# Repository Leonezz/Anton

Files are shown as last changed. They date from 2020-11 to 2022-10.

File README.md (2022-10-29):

# Anton

Anton is a custom keyboard project.

All what you need to build a keyboard is/will be in this repo.

## Details

Anton is a comtom design keyboard, it is based on STM32F103C8T6 MCU and QMK firmware. In this repo, all files(PCB, mechanical structure and code) are included.All what you need to do to make a same keyboard is clone all this files and make all things by taobao.com. 

# Features

- WS2812 RGB Lighting
- ~~Bluetooth(TODO)~~

# 2022-10-29 EDIT

After 4 keyboards made out this design and 2 years of use, I hereby announce this project a success.

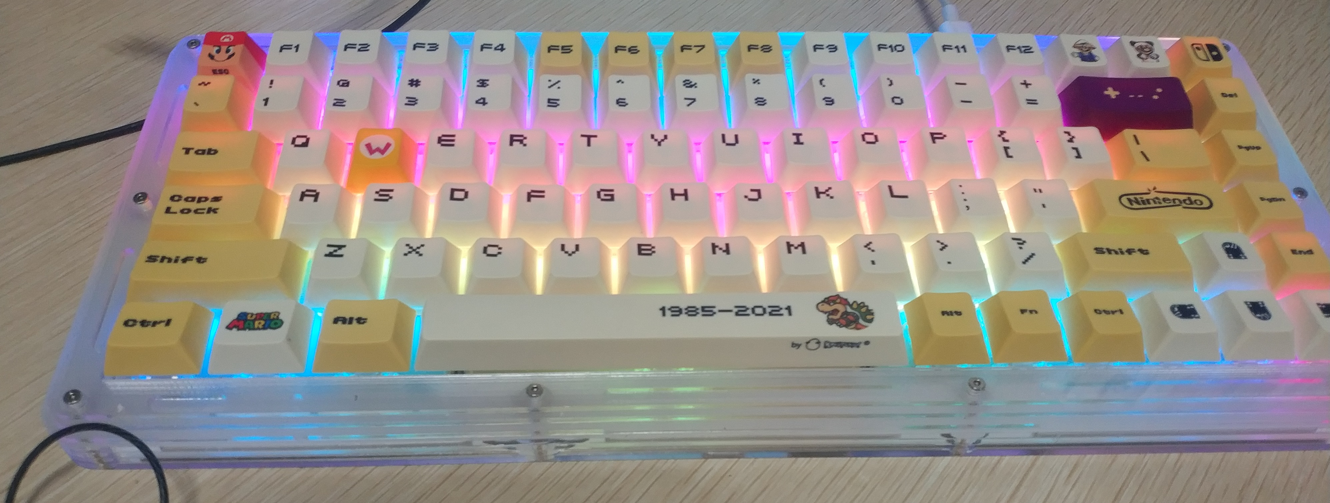
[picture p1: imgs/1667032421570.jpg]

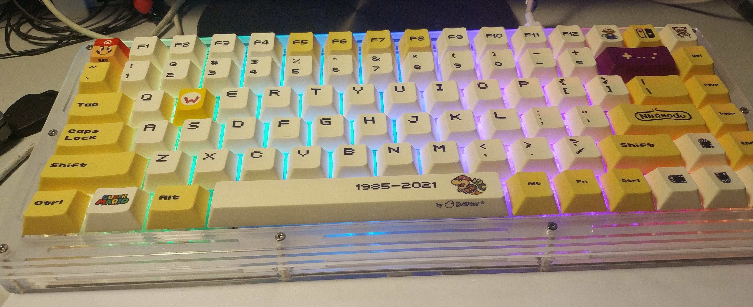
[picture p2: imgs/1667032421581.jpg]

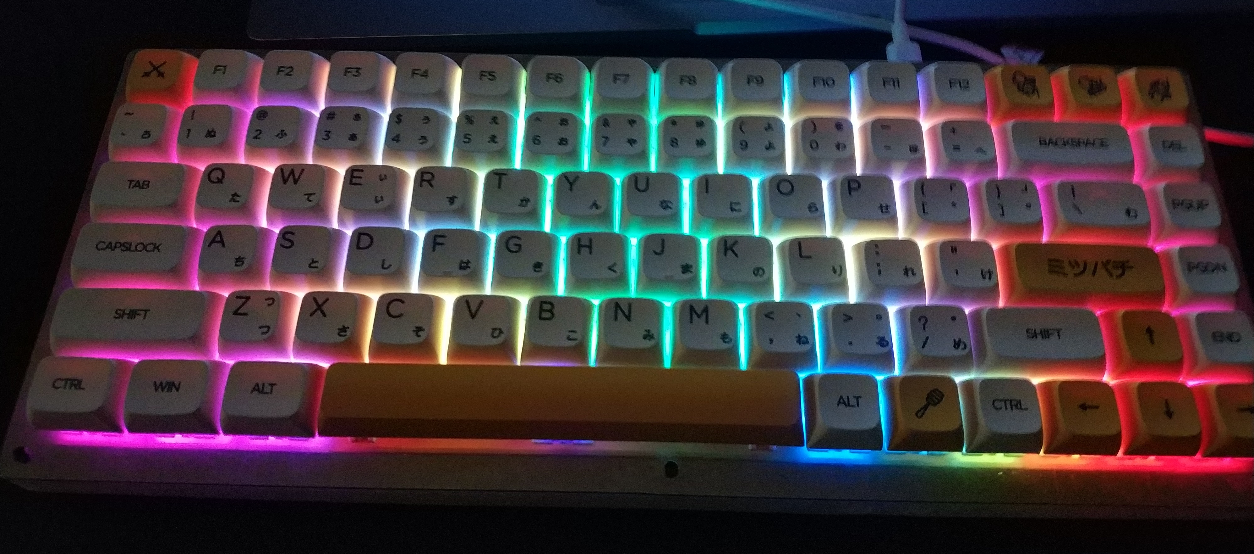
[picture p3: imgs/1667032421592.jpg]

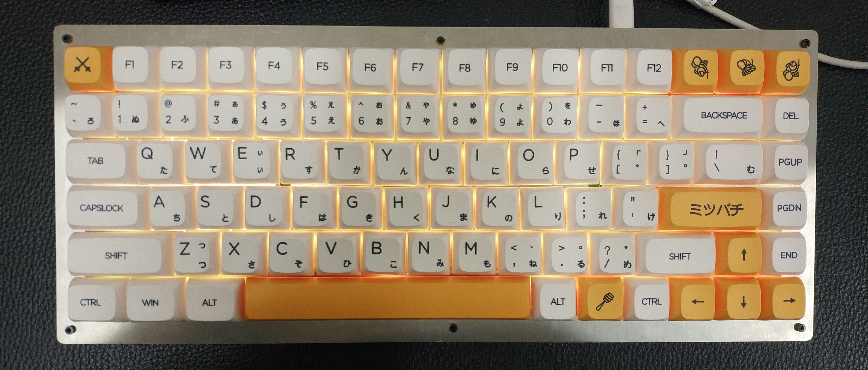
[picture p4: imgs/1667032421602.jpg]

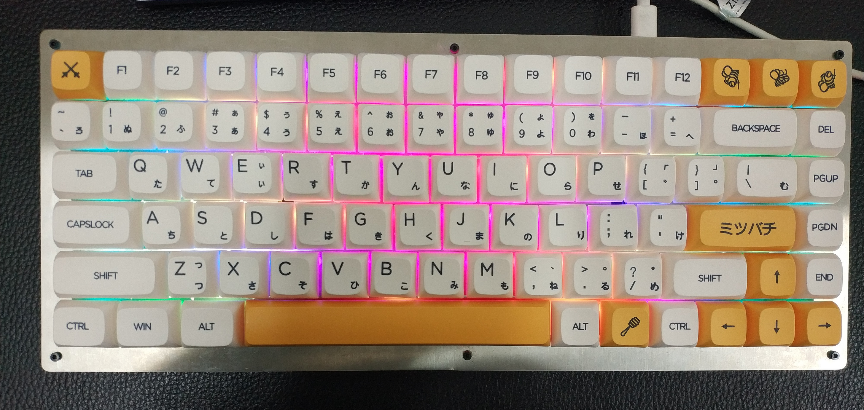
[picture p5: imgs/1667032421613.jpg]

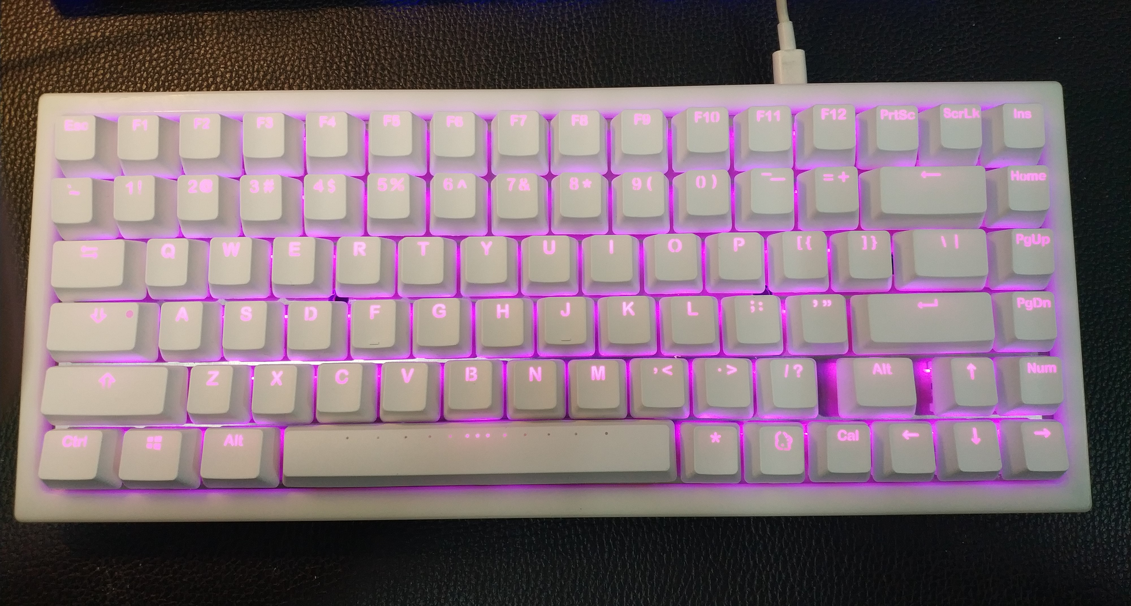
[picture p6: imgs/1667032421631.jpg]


# License

GPL

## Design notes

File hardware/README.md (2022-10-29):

# Hardware

keyboard hardware files, PCB circuit in folder `PCB` and shall 3D model in folder `structure`.

# Note

I am an amateur in all these design area,please check the files before actual manufacturing.

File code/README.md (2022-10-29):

keyboard firmware,running on stm32f103c8t6 MCU.

based on the opensource keyboard firmware [QMK](https://github.com/qmk/qmk_firmware)

the firmware for this very keyboard is [here](https://github.com/Leonezz/qmk_firmware/tree/master/keyboards/anton)

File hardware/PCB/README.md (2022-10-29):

# 使用立创EDA编辑

# Features

- Bluetooth
- type-c off board interface
- ws2812 RGB matrix
- hot swap switches

# What Can be Improved

- type-c sub board and battary interface too thin
- bluetooth module in bad position,it's batter to place it to the edge of board
- ws2812 package too tight,hard to put the element in
- swd download interface in bad position,better to the edge
- the on board power design is a failure, I have to use a off board one

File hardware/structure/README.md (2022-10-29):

# Structure

the shell 3D models are in this folder, you can use the stl files in folder `shell/stl` if you don't use `Solidworks`(all models are designed by it).

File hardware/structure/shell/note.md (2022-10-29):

轴:5mm
定位板:1.5mm
PCB:1.6mm
轴座:1.8mm

定位板下面到外壳上面至少:3.5+1.6+1.8 = 6.9

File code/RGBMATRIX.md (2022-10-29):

# REBMATRIX effects 中英文对照

```c
enum rgb_matrix_effects {
RGB_MATRIX_NONE = 0,
RGB_MATRIX_SOLID_COLOR = 1, // Static single hue, no speed support静态单色调无速度支持
RGB_MATRIX_ALPHAS_MODS, // Static dual hue, speed is hue for secondary hue静态双重色调速度为次要色调
RGB_MATRIX_GRADIENT_UP_DOWN, // Static gradient top to bottom, speed controls how much gradient changes静态渐变从上到下速度控制渐变量
RGB_MATRIX_GRADIENT_LEFT_RIGHT, // Static gradient left to right, speed controls how much gradient changes静态梯度从左到右速度控制梯度的变化量
RGB_MATRIX_BREATHING, // Single hue brightness cycling animation单色调亮度循环动画
RGB_MATRIX_BAND_SAT, // Single hue band fading saturation scrolling left to right左色调向右滚动单个色相带衰减饱和度
RGB_MATRIX_BAND_VAL, // Single hue band fading brightness scrolling left to right单个色相带衰减亮度从左向右滚动
RGB_MATRIX_BAND_PINWHEEL_SAT, // Single hue 3 blade spinning pinwheel fades saturation单色调3叶片旋转风车褪色饱和度
RGB_MATRIX_BAND_PINWHEEL_VAL, // Single hue 3 blade spinning pinwheel fades brightness单色调3叶片旋转风车减弱亮度
RGB_MATRIX_BAND_SPIRAL_SAT, // Single hue spinning spiral fades saturation单色调旋转螺旋褪色饱和度
RGB_MATRIX_BAND_SPIRAL_VAL, // Single hue spinning spiral fades brightness单色调旋转螺旋淡出亮度
RGB_MATRIX_CYCLE_ALL, // Full keyboard solid hue cycling through full gradient全键盘纯色在整个渐变中循环
RGB_MATRIX_CYCLE_LEFT_RIGHT, // Full gradient scrolling left to right从左到右全梯度滚动
RGB_MATRIX_CYCLE_UP_DOWN, // Full gradient scrolling top to bottom全梯度从上到下滚动
RGB_MATRIX_CYCLE_OUT_IN, // Full gradient scrolling out to in全梯度滚动到
RGB_MATRIX_CYCLE_OUT_IN_DUAL, // Full dual gradients scrolling out to in全双梯度滚动到
RGB_MATRIX_RAINBOW_MOVING_CHEVRON, // Full gradent Chevron shapped scrolling left to right全渐变雪佛龙形从左到右滚动
RGB_MATRIX_CYCLE_PINWHEEL, // Full gradient spinning pinwheel around center of keyboard围绕键盘中心的全梯度旋转风车
RGB_MATRIX_CYCLE_SPIRAL, // Full gradient spinning spiral around center of keyboard围绕键盘中心的全梯度旋转螺旋
RGB_MATRIX_DUAL_BEACON, // Full gradient spinning around center of keyboard全梯度围绕键盘中心旋转
RGB_MATRIX_RAINBOW_BEACON, // Full tighter gradient spinning around center of keyboard围绕键盘中心的旋转更加紧密
RGB_MATRIX_RAINBOW_PINWHEELS, // Full dual gradients spinning two halfs of keyboard全双梯度旋转两半键盘
RGB_MATRIX_RAINDROPS, // Randomly changes a single key's hue随机更改单个键的色调
RGB_MATRIX_JELLYBEAN_RAINDROPS, // Randomly changes a single key's hue and saturation随机更改单个键的色相和饱和度
#if define(RGB_MATRIX_FRAMEBUFFER_EFFECTS)
RGB_MATRIX_TYPING_HEATMAP, // How hot is your WPM!您的WPM有多热
RGB_MATRIX_DIGITAL_RAIN, // That famous computer simulation那著名的计算机模拟
#endif
#if defined(RGB_MATRIX_KEYPRESSES) || defined(RGB_MATRIX_KEYRELEASES)
RGB_MATRIX_SOLID_REACTIVE_SIMPLE, // Pulses keys hit to hue & value then fades value out脉冲键击中色相和值然后淡出值
RGB_MATRIX_SOLID_REACTIVE, // Static single hue, pulses keys hit to shifted hue then fades to current hue静态单一色相脉冲键敲击以改变色相然后淡出为当前色相
RGB_MATRIX_SOLID_REACTIVE_WIDE // Hue & value pulse near a single key hit then fades value out一次按键时的色相和数值脉冲然后淡出数值
RGB_MATRIX_SOLID_REACTIVE_MULTIWIDE // Hue & value pulse near multiple key hits then fades value out多次击键时的色相和数值脉冲然后淡出数值
RGB_MATRIX_SOLID_REACTIVE_CROSS // Hue & value pulse the same column and row of a single key hit then fades value out色相和值在一次击键时以相同的列和行脉冲然后淡出值
RGB_MATRIX_SOLID_REACTIVE_MULTICROSS // Hue & value pulse the same column and row of multiple key hits then fades value out色相和值在多个击键的相同列和行上脉冲然后淡出值
RGB_MATRIX_SOLID_REACTIVE_NEXUS // Hue & value pulse away on the same column and row of a single key hit then fades value out色相和数值在一次击键的同一列和同一行上消失然后淡出数值
RGB_MATRIX_SOLID_REACTIVE_MULTINEXUS // Hue & value pulse away on the same column and row of multiple key hits then fades value out色相和值在多个击键的同一列和同一行上消失然后淡出值
RGB_MATRIX_SPLASH, // Full gradient & value pulse away from a single key hit then fades value out完整的梯度和数值脉冲远离单个按键然后淡出数值
RGB_MATRIX_MULTISPLASH, // Full gradient & value pulse away from multiple key hits then fades value out完整的渐变和价值脉冲远离多个击键然后淡出价值
RGB_MATRIX_SOLID_SPLASH, // Hue & value pulse away from a single key hit then fades value out色相和价值脉冲远离单个击键然后淡出价值
RGB_MATRIX_SOLID_MULTISPLASH, // Hue & value pulse away from multiple key hits then fades value out色相和价值脉冲远离多个击键然后淡出价值
#endif
RGB_MATRIX_EFFECT_MAX
};
```

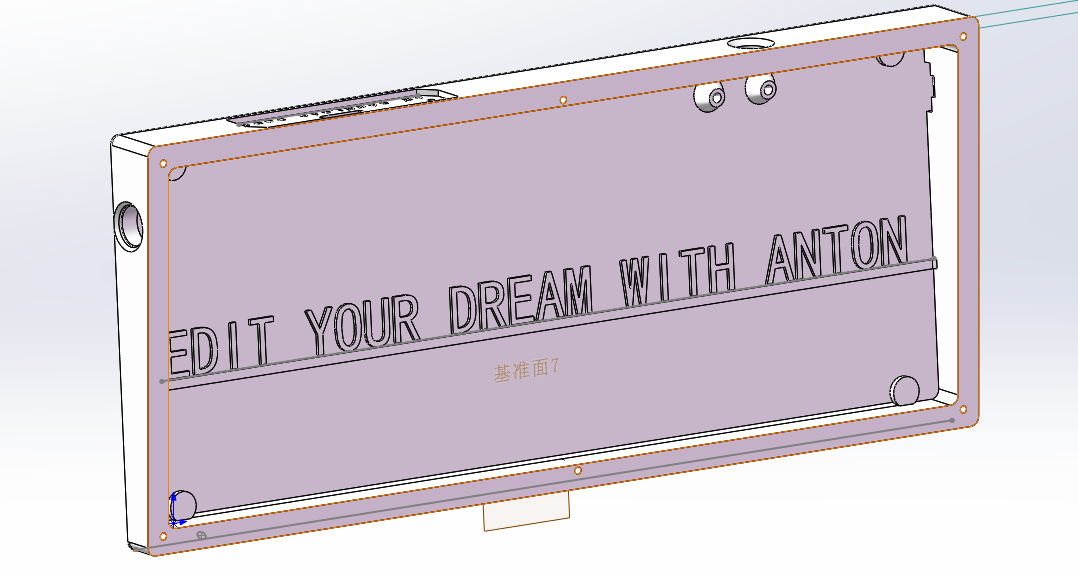
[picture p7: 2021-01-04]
hardware/structure/shell/imgs/down.png

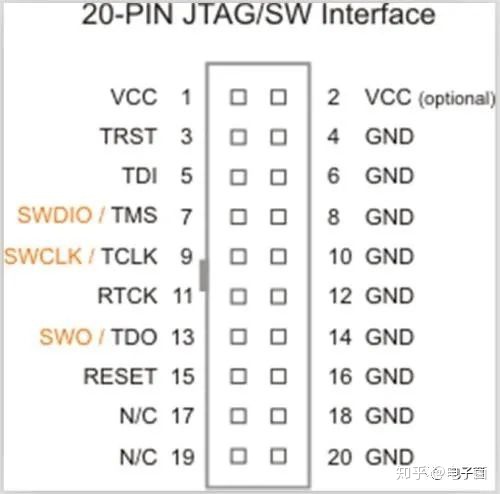
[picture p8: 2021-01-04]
hardware/structure/img/J-Tag.jpg

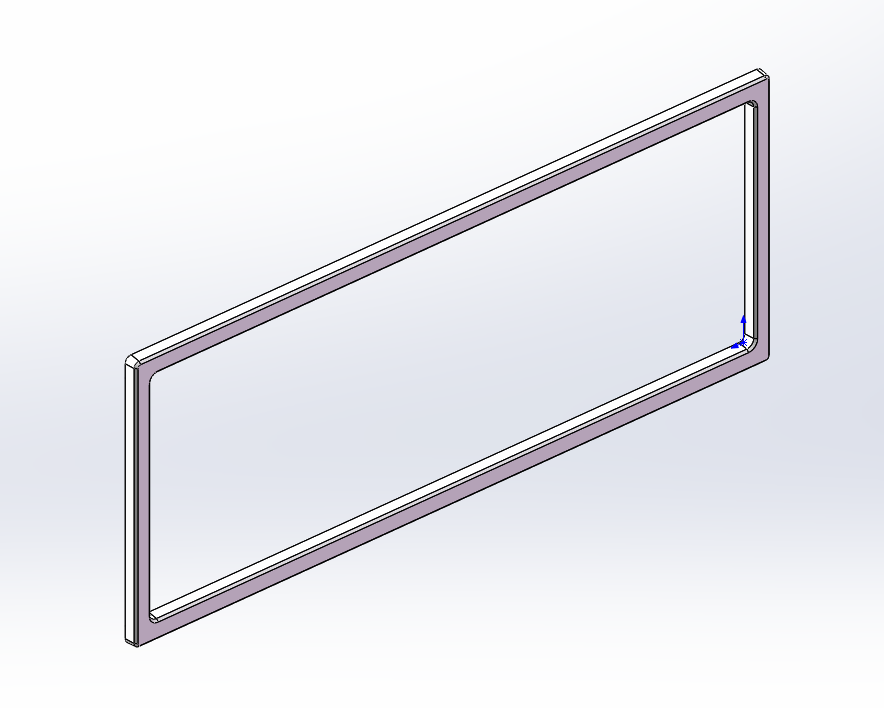
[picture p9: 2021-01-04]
hardware/structure/shell/imgs/up.png

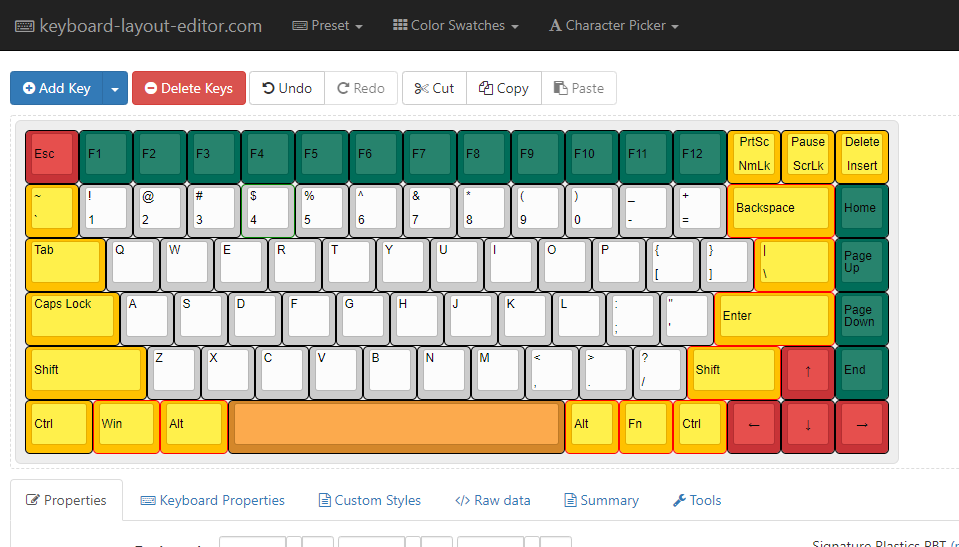
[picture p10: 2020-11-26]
hardware/structure/img/look.jpg

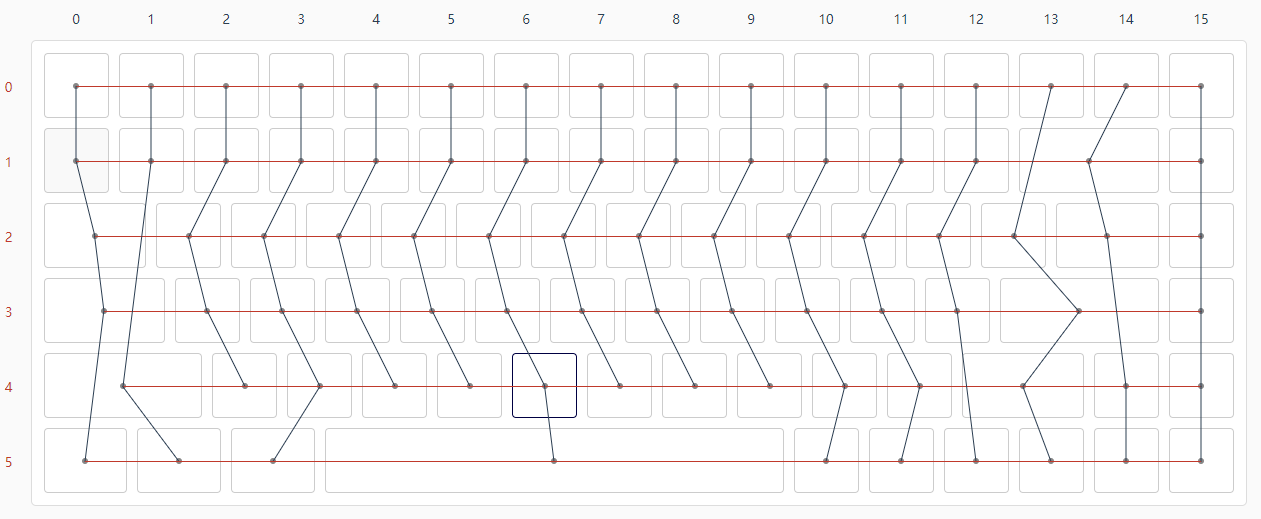
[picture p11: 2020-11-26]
hardware/structure/matrix.png

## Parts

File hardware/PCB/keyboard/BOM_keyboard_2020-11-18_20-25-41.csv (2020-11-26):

ID | Name | Designator | Footprint | Quantity | Manufacturer Part | Manufacturer | Supplier | Supplier Part | _Price | LCSC Assembly
1 | Switch3x4x2 | BOOT,RESET | KEY-3.0*4.0 | 2 | Switch3x4x2 | ReliaPro | LCSC | C26638 | ￥0.21811
2 | 10K | R11 | R0805 | 1 | TR0805B10KP0525 | Ever Ohms Tech | LCSC | C188360 | ￥0.118193
3 | 2.54MM-4P | H1 | HDR-TH_4P-P2.54-V | 1 | 210-91-04GB01 | PINREX | LCSC | C390680 | ￥0.068036
4 | MF-NSMF050-2 | FF | F1206 | 1 | MF-NSMF050-2 | BOURNS | LCSC | C75464 | ￥0.185259 | Yes
5 | btk-05 | M1 | BTK-05-BLUTEETH | 1
6 | 300 | R10 | R0805 | 1 | RMCF0805JT300R | Stackpole Elec | LCSC | C237136 | ￥0.042691
7 | LED0805-GD | STDBY_LED | LED0805-RD | 1 | LED0805-GD | ARKLED | LCSC | C107402 | ￥0.0835 | Yes
8 | CHERRYMX 2U 卫星轴 COPY | K2 | CHERRY_MX_2U_卫星轴 | 1 | Cherry MX
9 | 100nF | C18,C16,C20,C7,C9,C17 | C0603 | 6 | GRM188R11C104KA01D | MuRata | LCSC | C86004 | ￥0.105227
10 | 10uH | L1 | IND-SMD_L4.6-W4.1 | 1 | MHCI04020-100M-R8 | Chilisin Elec | LCSC | C285744 | ￥2
11 | 22 | R1,R2 | R0603 | 2 | 0603WAF220JT5E | UniOhm | LCSC | C23345 | ￥0.005856 | Yes
12 | FC-2012HYK-588J | LED5 | LED0805-FD | 1 | FC-2012HYK-588J | NATIONSTAR | LCSC | C84261 | ￥0.117 | Yes
13 | 22uF | C25,C24 | C1206 | 2 | CL31A226KOHNNNE | SAMSUNG | LCSC | C90146 | ￥0.209598 | Yes
14 | STM32F103C8T6 | U5 | LQFP-48_L7.0-W7.0-P0.50-LS9.0-BL | 1 | STM32F103C8T6 | STMicroelectronics | LCSC | C8734 | ￥14.18 | Yes
15 | 1.25T-4PWT | CN2 | CONN-SMD_4P-P1.25_1.25T-4PWT | 1 | 1.25T-4PWT | BOOMELE | LCSC | C31597 | ￥0.238058
16 | FC-2012HRK-620D | LED7 | LED0805-RD | 1 | FC-2012HRK-620D | NATIONSTAR | LCSC | C84256 | ￥0.1105 | Yes
17 | A1254WR-S-2P | U3 | CONN-SMD_A1254WR-S-2P | 1 | A1254WR-S-2P | Changjiang Connectors | LCSC | C272975 | ￥1.5
18 | 22pF | C14,C15 | C0805 | 2 | 0805CG220J500NT | FH | LCSC | C24658 | ￥0.03805
19 | 1uF | C1,C2 | C0603 | 2 | CL10A105KB8NNNC | SAMSUNG | LCSC | C15849 | ￥0.041494 | Yes
20 | SOD4002-SH | D167,D166,D165,D164,D163,D162,D161,D160,D159,D158,D157,D156,D155,D154,D153,D152,D151,D143,D150,D149,D85,D1,D86,D87,D88,D89,D90,D91,D92,D93,D94,D95,D96,D97,D98,D99,D100,D101,D102,D103,D104,D105,D106,D107,D108,D109,D110,D111,D112,D113,D114,D115,D116,D117,D118,D119,D120,D121,D122,D123,D124,D125,D126,D127,D128,D129,D130,D131,D132,D133,D134,D135,D136,D137,D138,D139,D140,D141,D142,D148,D144,D145,D146,D147 | SOD-123F_L2.8-W1.8-LS3.7-RD | 84 | SOD4002-SH | LRC | LCSC | C154996 | ￥0.1185 | Yes
21 | FC-A2012BK-470H2 | LED4 | LED0805-RD | 1 | FC-A2012BK-470H2 | NATIONSTAR | LCSC | C84259 | ￥0.13 | Yes
22 | TP5400 | U7 | SOIC-8_L5.0-W4.0-P1.27-LS6.0-BL-EP | 1 | TP5400 | TOPPOWER | LCSC | C24154 | ￥1.1846 | Yes
23 | LM1117S-3.3 | U6 | SOT-223-3_L6.5-W3.4-P2.30-LS7.0-BR | 1 | LM1117S-3.3 | HTC | LCSC | C126027 | ￥1 | Yes
24 | PRTR5V0U2X | D2 | SOT-143_L2.9-W1.3-P1.92-LS2.3-BL | 1 | PRTR5V0U2X | Yenji Elec | LCSC | C330092 | ￥0.4999
25 | 1.1K | R12 | R0805 | 1 | 0805W8J0112T5E | Uniroyal Elec | LCSC | C246845 | ￥0.011479
26 | SS34_C432300 | D3 | SMA_L4.4-W2.8-LS5.4-RD | 1 | SS34 | LGE | LCSC | C432300 | ￥0.22135 | Yes
27 | 12MHz | X2 | HC-49S_L11.4-W4.8 | 1 | XJHCELNANF-12MHZ | TAITIEN Elec | LCSC | C295091 | ￥0.82
28 | 220uF | C6 | CAP-SMD_BD8.0-L8.3-W8.3-FD | 1 | RVT1C221M0806 | HONOR | LCSC | C86608 | ￥0.501117
29 | CHERRYMX 6.25U 卫星轴 COPY | K1 | CHERRY_MX_6.25 | 1 | CherryMX
30 | 100nF | C19,C23 | C0603 | 2 | CT41-0603-2F4-50V-0.1uF-M(N) | TORCH | LCSC | C138344 | ￥0.059988
31 | 1.5K | R13 | R0805 | 1 | 0805W8F1501T5E | UniOhm | LCSC | C4310 | ￥0.017242 | Yes
32 | PCB卫星轴_2.25U | U2,U1 | PCB卫星轴__2.25U | 2
33 | 倒置3528-REVERSE | KEY_3,KEY_2,KEY_1,CAPSLOCK,KEY_A,KEY_S,KEY_D,KEY_F,KEY_G,KEY_H,KEY_J,KEY_K,KEY_L,KEY_;,KEY_',FN,PAGEDOWN,RIGHT,DOWN,LEFT,RIGHT_CTRL,HOME,RIGHT_ALT,SPACE,LEFT_ALT,WIN,LEFT_CTRL,KEY_~,BACKSPACE,KEY_=,KEY_-,KEY_0,KEY_9,KEY_8,KEY_7,KEY_6,KEY_5,KEY_4,ENTER | 3528热插拔灯倒置 | 39 | CherryMX
34 | 10uF | C22 | C0805 | 1 | 0805X106K100NT | FH | LCSC | C90543 | ￥0.135175
35 | 47uF | C21,C8 | CAP-SMD_L3.5-W2.8-R-RD | 2 | CA45-B-10V-47UF-K | CEC | LCSC | C136658 | ￥1 | Yes
36 | 1k | R14,R9,R8 | R0805 | 3
37 | 倒置3528 | E,W,Y,U,N,M,B,T,R,],PAGEUP,\,P,[,O,V,I,F8,F9,F11,END,UP,F10,PAUSE,/,RIGHT_SHIFT,.,DELETE,PTRSC,,,F12,TAB,Q,F4,F1,LEFT_SHIFT,F5,F7,F6,Z,F2,C,F3,X,ESC | 3528热插拔灯倒置-NEW | 45 | CherryMX

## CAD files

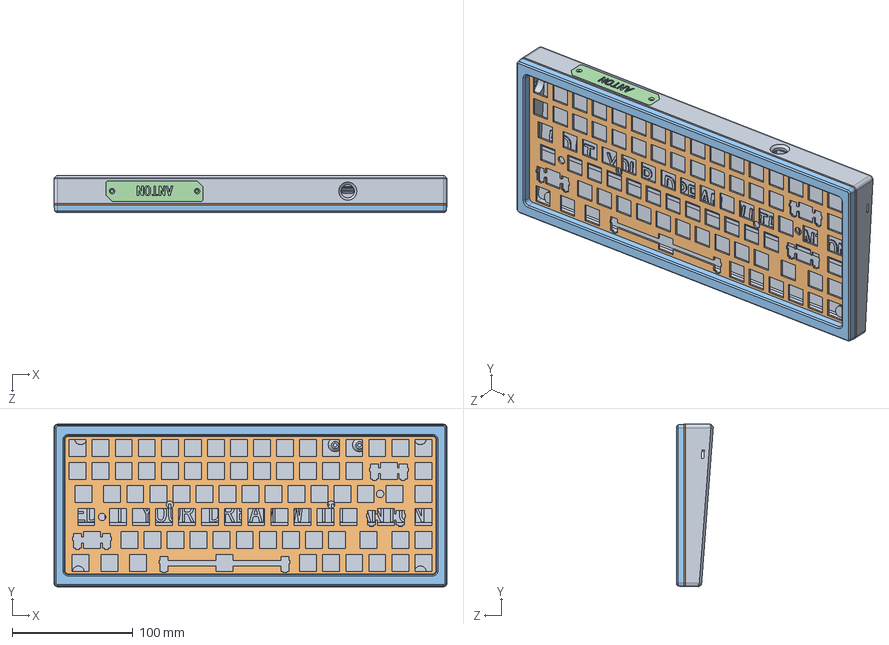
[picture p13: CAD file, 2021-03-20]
hardware/structure/shell/assembly.SLDASM
324.8 x 134.4 x 30.3 mm
downV2
plate
up
logo

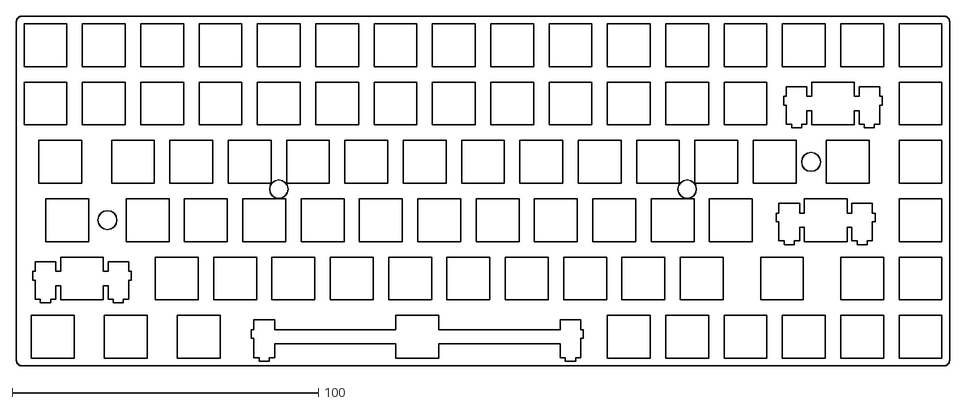
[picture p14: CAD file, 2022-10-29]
hardware/structure/plate/layout.dxf
304.8 x 114.3

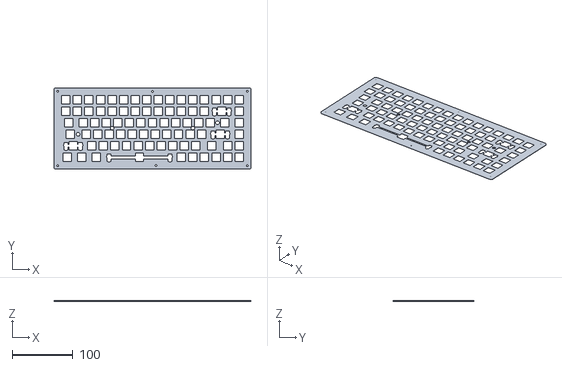
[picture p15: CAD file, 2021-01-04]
hardware/structure/shell/stl/装配 - 定位板-2.STL
324.8 x 134.3 x 1.50

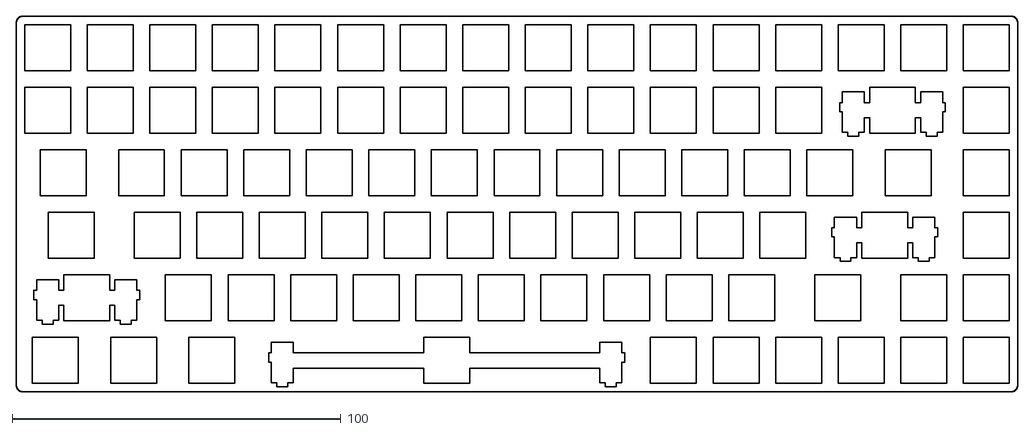
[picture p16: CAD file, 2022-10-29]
hardware/structure/plate/layout - cp.dxf
304.8 x 114.3

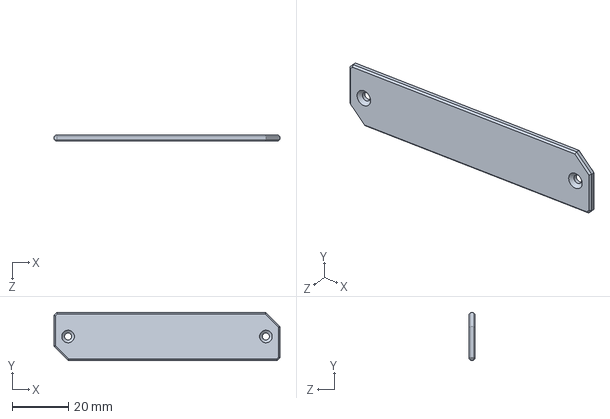
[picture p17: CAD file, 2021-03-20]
hardware/structure/shell/logo.SLDPRT
80.3 x 17.1 x 2.00 mm

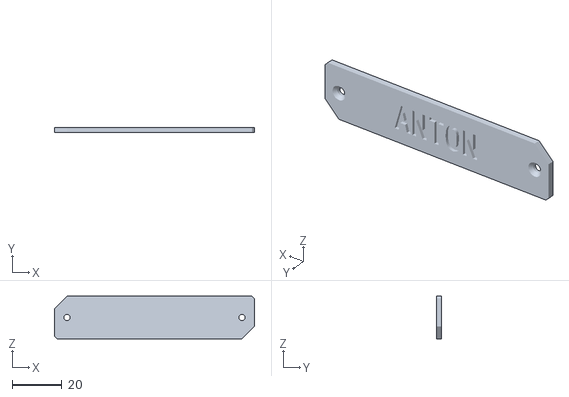
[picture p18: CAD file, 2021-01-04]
hardware/structure/shell/stl/装配 - logo-2.STL
80.3 x 2.00 x 17.1

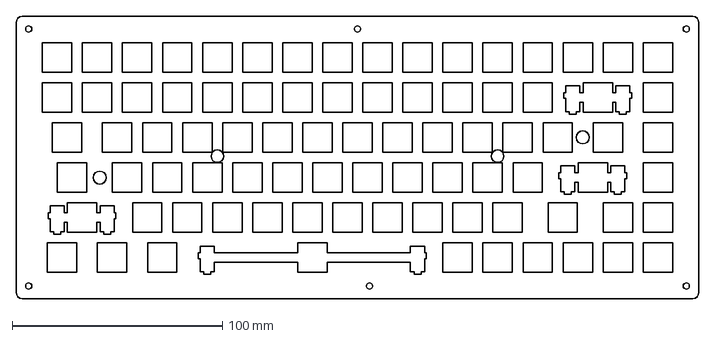
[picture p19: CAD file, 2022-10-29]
hardware/structure/plate/定位板.DXF
324.8 x 134.3 mm

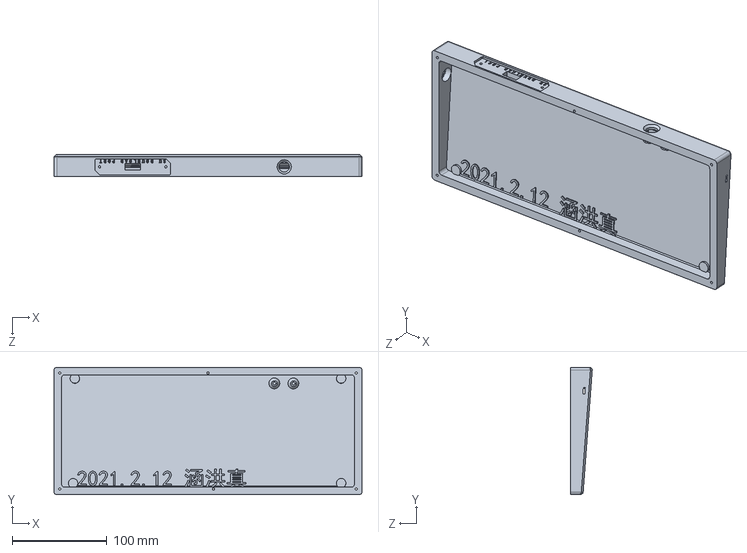
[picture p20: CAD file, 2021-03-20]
hardware/structure/shell/downV2.SLDPRT
324.8 x 134.4 x 22.8 mm

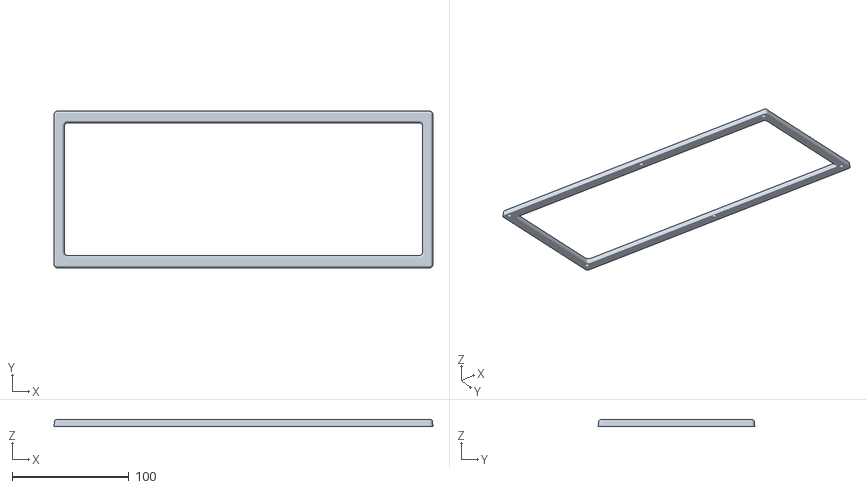
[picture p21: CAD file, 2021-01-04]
hardware/structure/shell/stl/装配 - 上壳-1.STL
324.8 x 134.3 x 6.00

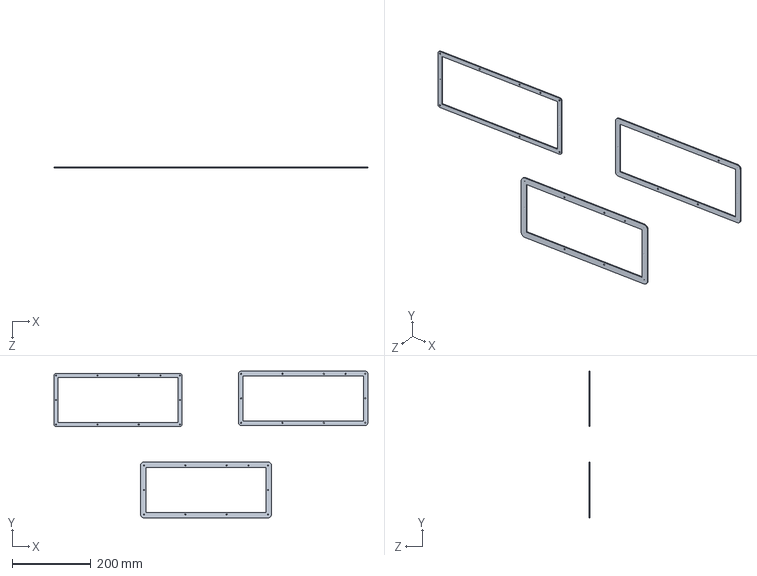
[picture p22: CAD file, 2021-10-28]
hardware/structure/PCStack/top_layer_3.SLDPRT
796.2 x 372.5 x 2.50 mm

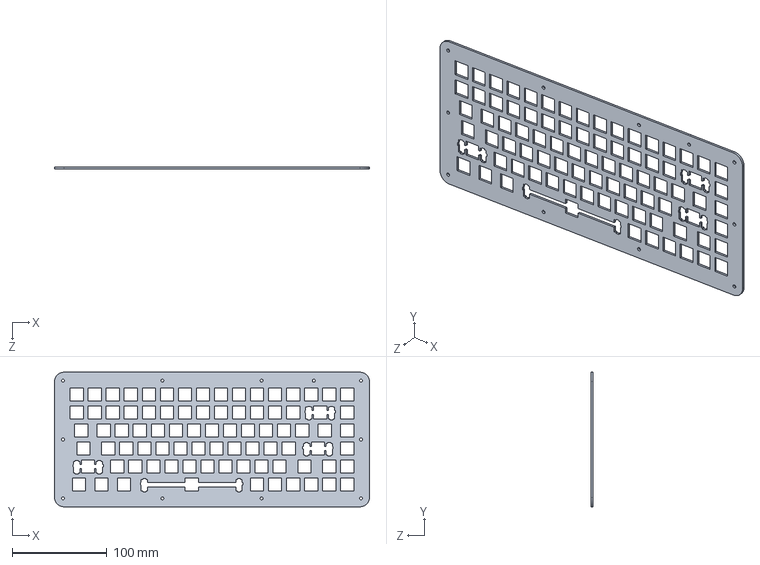
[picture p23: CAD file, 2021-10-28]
hardware/structure/PCStack/switch_layer_3.SLDPRT
332.8 x 142.3 x 2.00 mm

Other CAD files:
hardware/structure/PCStack/stack.SLDPRT
hardware/structure/PCStack/switch_layer.SLDPRT
hardware/structure/PCStack/bottom_layer.SLDPRT
hardware/structure/shell/stl/装配 - 下壳-1.STL
hardware/structure/PCStack/open_layer.SLDPRT
hardware/structure/shell/up.SLDPRT
hardware/structure/shell/plate.SLDPRT
hardware/structure/PCStack/bottom_layer.dxf
hardware/structure/PCStack/bottom_layer_3.SLDPRT
hardware/structure/PCStack/closed_layer.SLDPRT
hardware/structure/PCStack/closed_layer.dxf
hardware/structure/PCStack/open_layer.dxf
hardware/structure/PCStack/open_layer_3.SLDPRT
hardware/structure/PCStack/switch_layer.dxf
hardware/structure/PCStack/switch_layer_none.dxf
hardware/structure/PCStack/top_layer.SLDPRT
hardware/structure/PCStack/top_layer.dxf
hardware/structure/shell/down.SLDPRT
hardware/structure/shell/stl/downV2.STL

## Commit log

2020-11-26 :tada: init repo
    [BOM_keyboard_2020-11-18_20-25-41.csv, layout - cp.dxf, layout.dxf]
2021-01-04 this commit message is edited with Anton
    [BOM_keyboard_2020-11-18_20-25-41.csv, assembly.SLDASM, down.SLDPRT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]
2021-03-20 add new logo svg & AI file. add qmk submodule.
    [assembly.SLDASM, downV2.SLDPRT, downV2.STL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]
2021-10-28 add acrylic shell design
    [bottom_layer.SLDPRT, bottom_layer.dxf, bottom_layer_3.SLDPRT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]
2021-10-28 update arclyc stack
    [bottom_layer.SLDPRT, open_layer.SLDPRT, stack.SLDPRT]
